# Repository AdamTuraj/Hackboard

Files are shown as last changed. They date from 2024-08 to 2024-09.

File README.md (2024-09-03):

# Title Saying Hackboard

**Every hardware hacker needs a development board. So why not make your own overkill one?**

The Hackboard is a "one board fits (almost) all" development board with many useful features to ensure it works with all projects! Whether you need to drive a motor, listen through a microphone, play music on a speaker or use various peripherals, the Hackboard has you covered.

Running on Arduino or STM32CubeIDE, you can take full advantage of Hackboard due to its low learning curve. On top of all these features, it is super efficient and can easily run off a 9v battery for many hours. Still not interested. Get a larger overview of the features below!

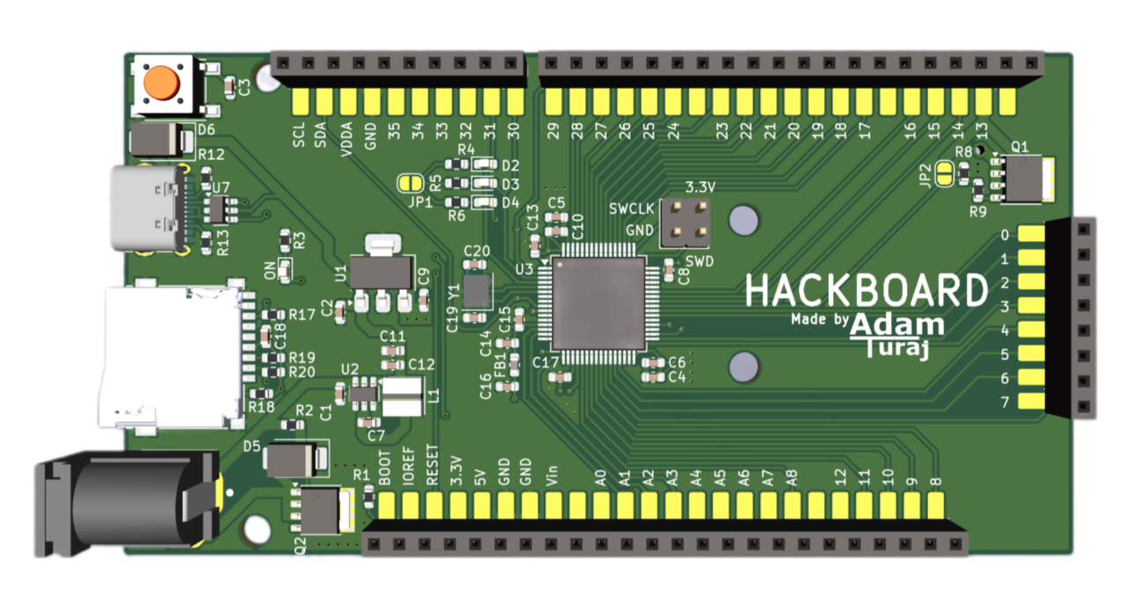
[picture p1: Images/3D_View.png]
A Top 3d view of the hackboard


Here's a deeper dive into the features:

- 80MHz Cortex M4 Core with 1 Mb of Flash and 128 Kb of SRAM
- Abilitiy to run on a 9v battery for around **150 HOURS**[^1]
- 45 GPIO pins
  - 2 SPI Interfaces[^2]
  - 1 I2C Interface
  - 1 CAN Interface
  - 1 UART Interface
  - 18 PWM Pins
  - 9 ADC's (Analog pins)
  - 2 DAC's
  - 1 OPAmp
- Arduino Uno Shield Compatible
- Same hole arrangement as Arduino UNO[^3]
- Extended header pads for easy probing
- Micro SD card slot
- PWM Addressable MOSFET capable of powering up to 54W
- 3 addressable LED's
- Barrel jack supporting up to 32V at 54W
- USB C port for flashing and power

[^1]: This assumes you are running with 0 peripherals connected, and are using a [Duracell 9v battery](https://www.duracell.com/wp-content/uploads/2016/03/MN1604_US_CT1.pdf)
[^2]: Only one may be used when an SD card is in use.
[^3]: The bottom right hole moved slightly up due to spacing issues.

## Assembly

> [!WARNING]
> This board CANNOT be assembled through JLCPCB due to many of the parts not being available at LCSC. Alternatives are using different PCB manufacturers or assembling it yourself

The BOM can be found in the production folder or the Digikey list [here](https://www.digikey.ca/en/mylists/list/BNXJM32ETT).

The extra MOSFET and related circuitry on pin 13 does not need to be soldered for the board to function (hence the DNP).

### Jumpers

JP1 and JP2 are jumpers that can be soldered/desoldered to achieve certain functionality.

JP1 must be bridged to enable the addressable LED's. JP2 must be left unbridged if the MOSFET is soldered.

### Work with Arduino

> [!NOTE]
> You must have an STLink to continue. They can be bought standalone or with a Nucleo board

A more detailed guide will be written up shortly. For now you may use [STM32Duino](https://github.com/stm32duino/Arduino_Core_STM32) to make it work with Arduino.

## Images

Schematic
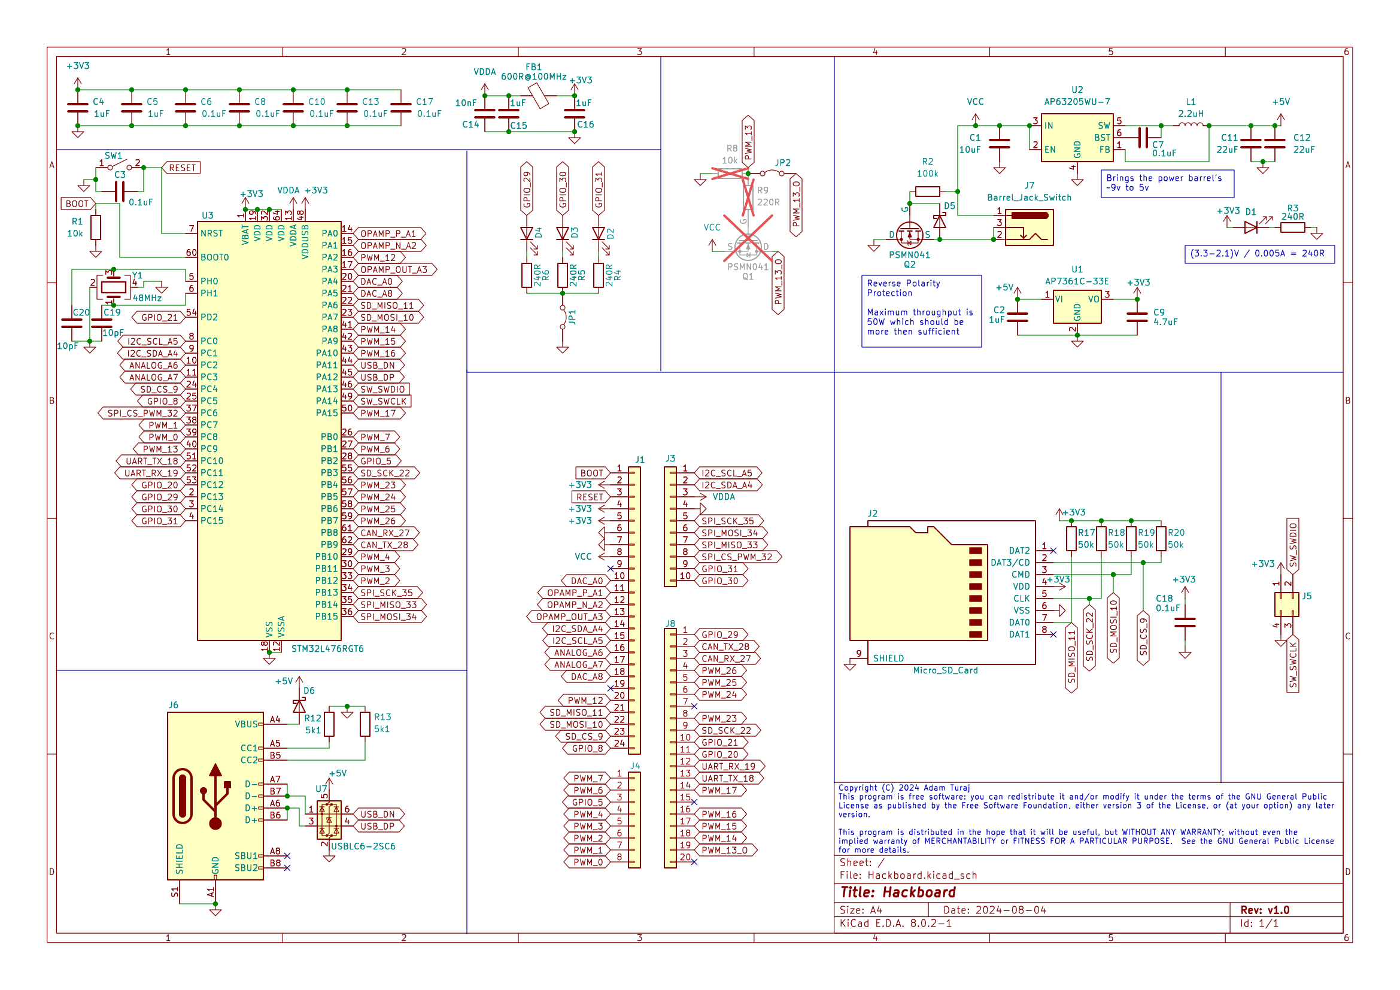
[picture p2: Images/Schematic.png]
Schematic


All Layers
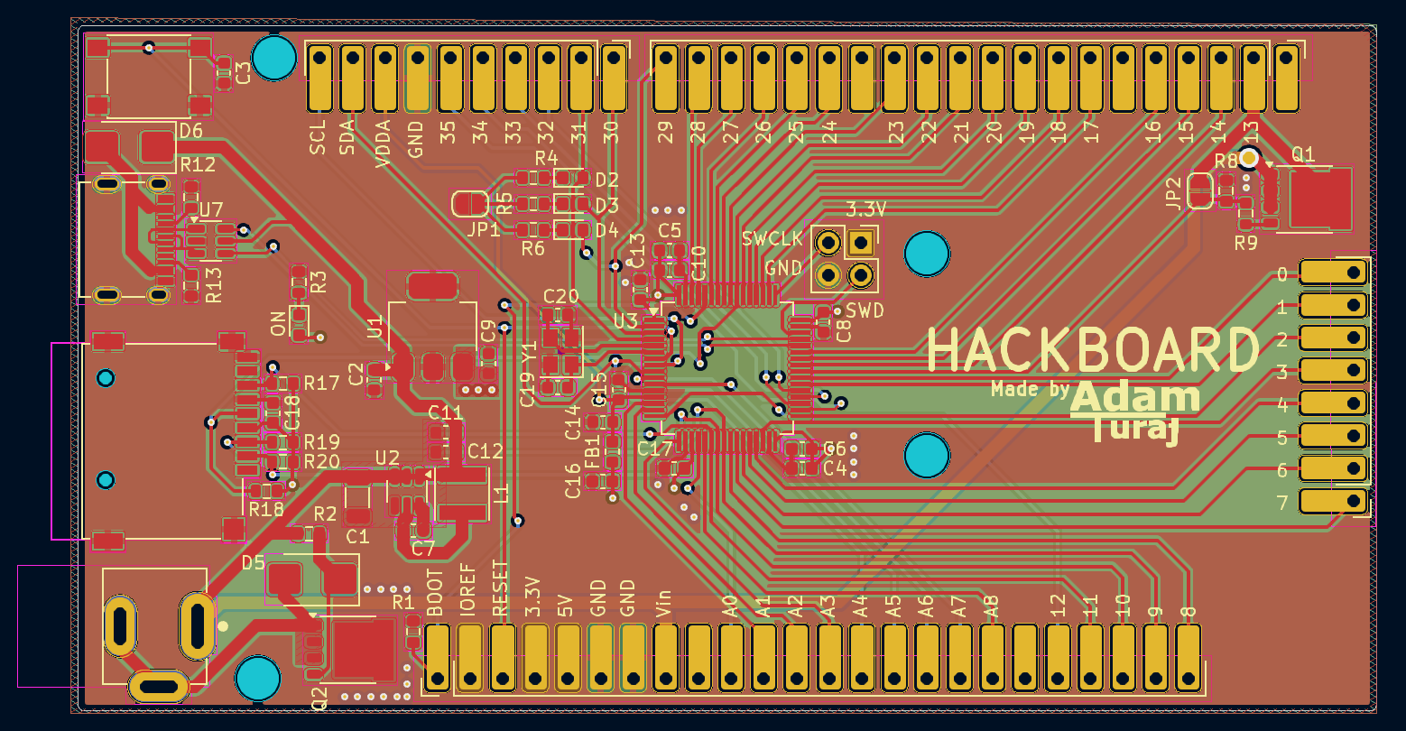
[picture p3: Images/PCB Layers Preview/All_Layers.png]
All PCB Layers


Top Layer (Signal / GND)
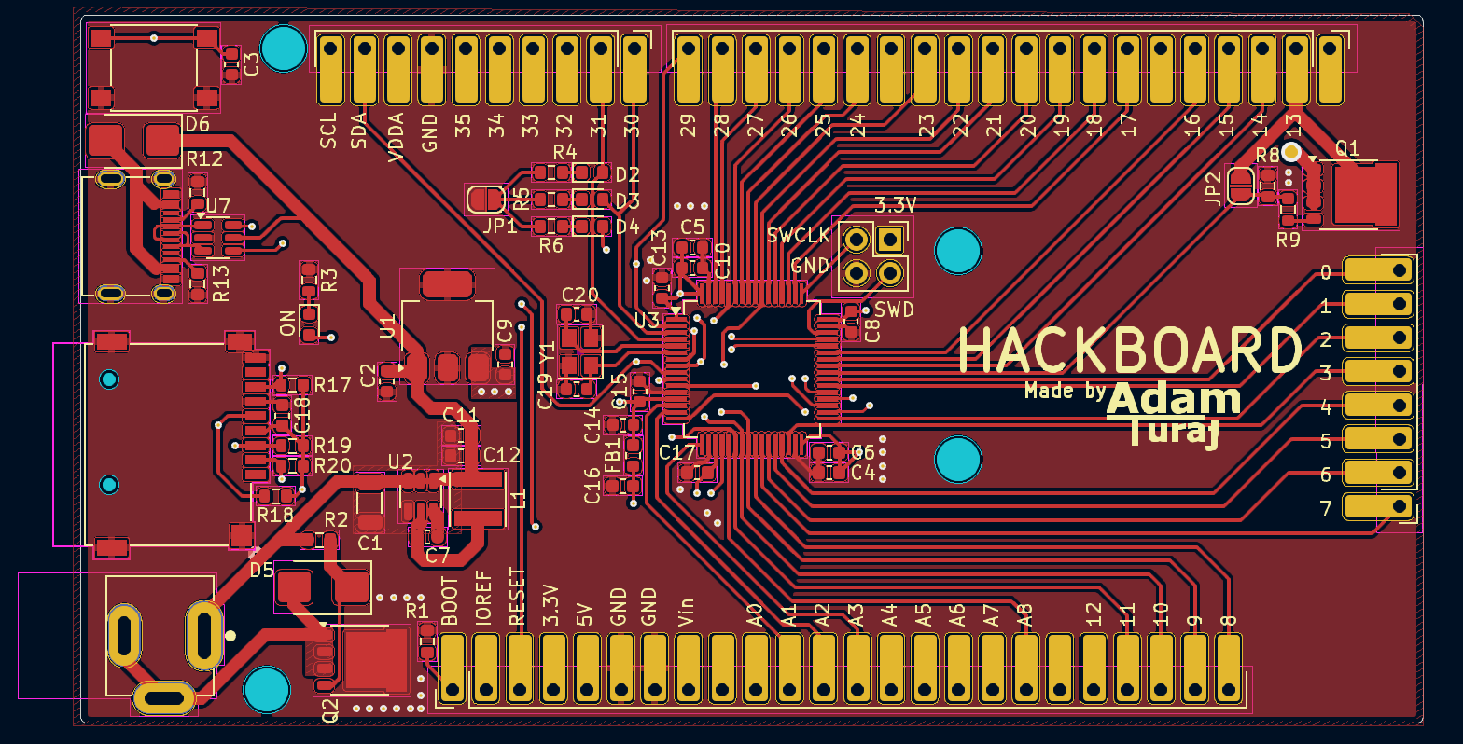
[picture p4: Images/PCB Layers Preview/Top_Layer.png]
Top PCB Layer


Second Layer (GND)
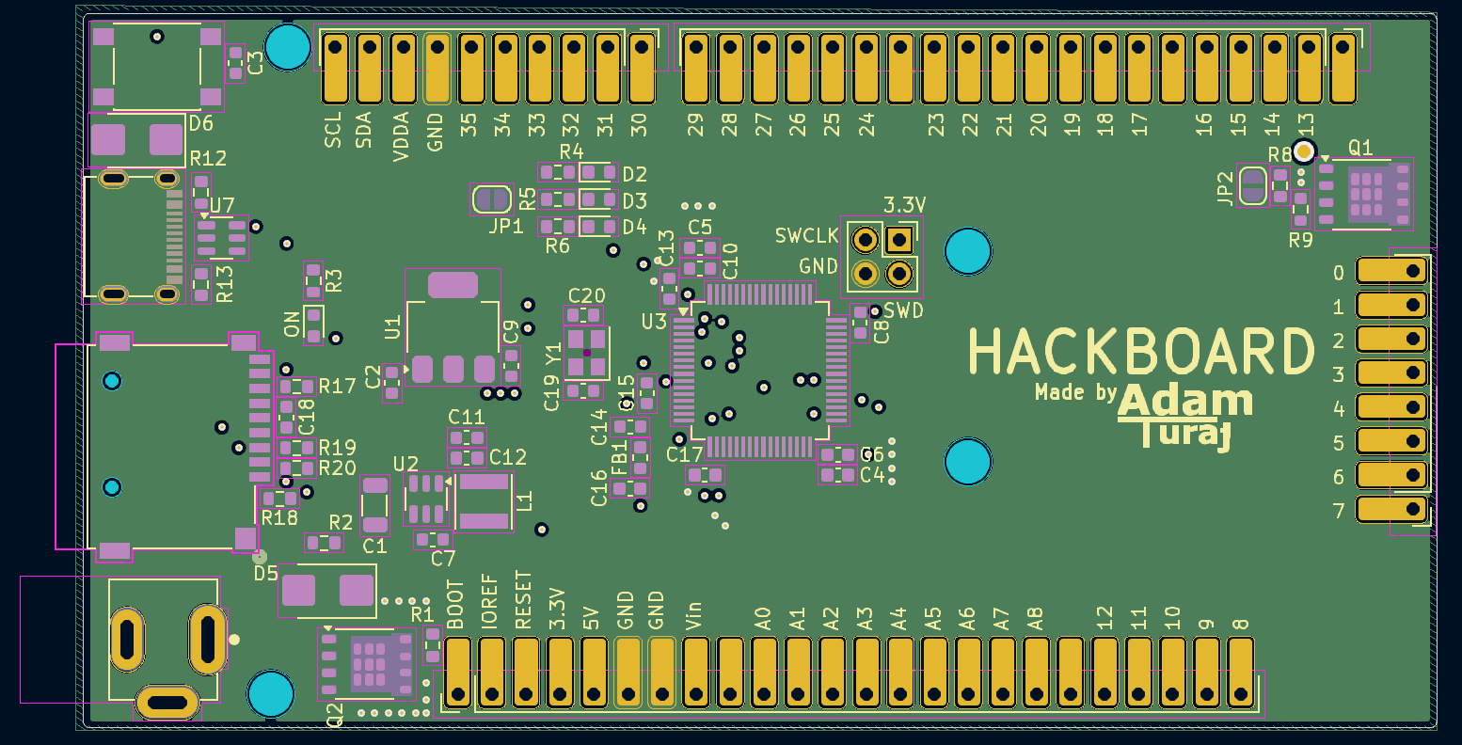
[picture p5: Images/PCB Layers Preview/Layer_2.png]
Second PCB Layer


Third Layer (Power)
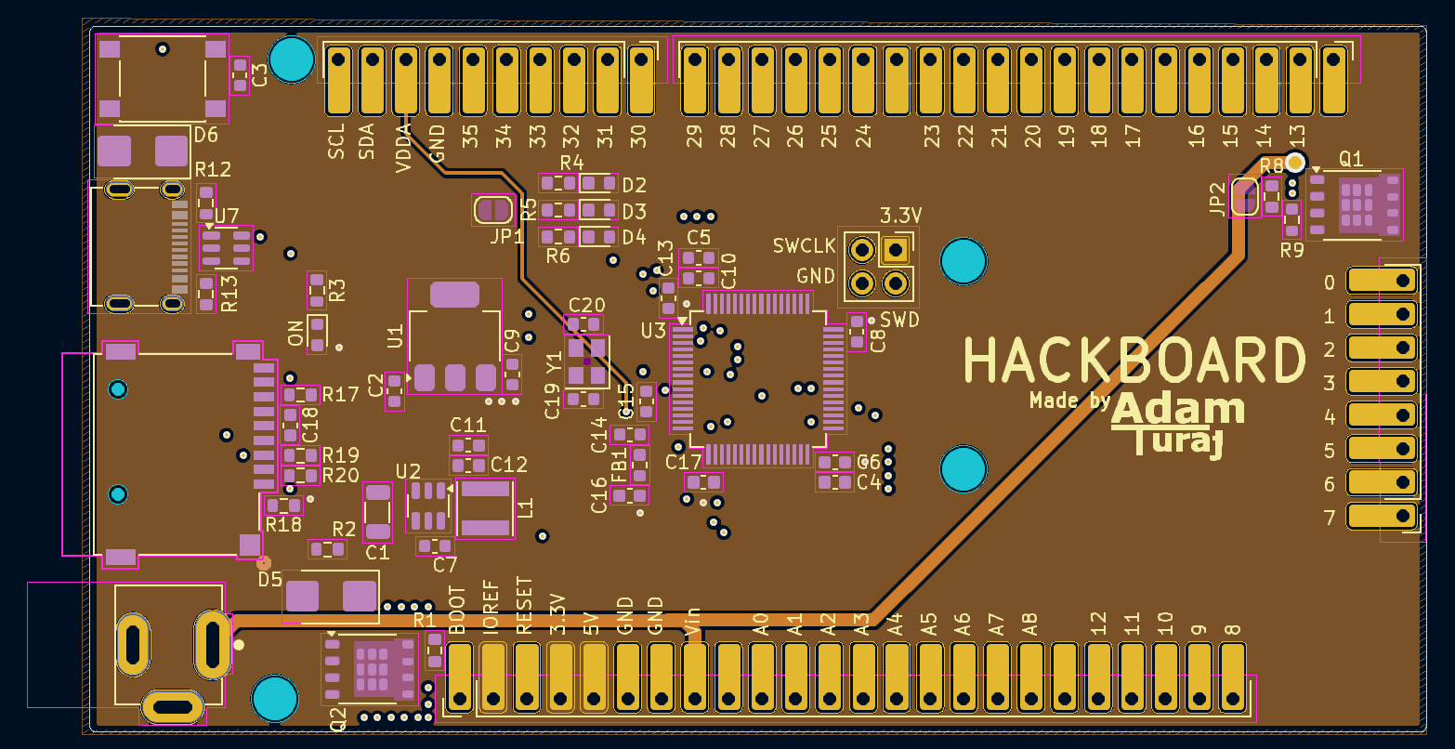
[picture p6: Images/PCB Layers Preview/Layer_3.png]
Third PCB Layer


Bottom Layer (Signal / GND)
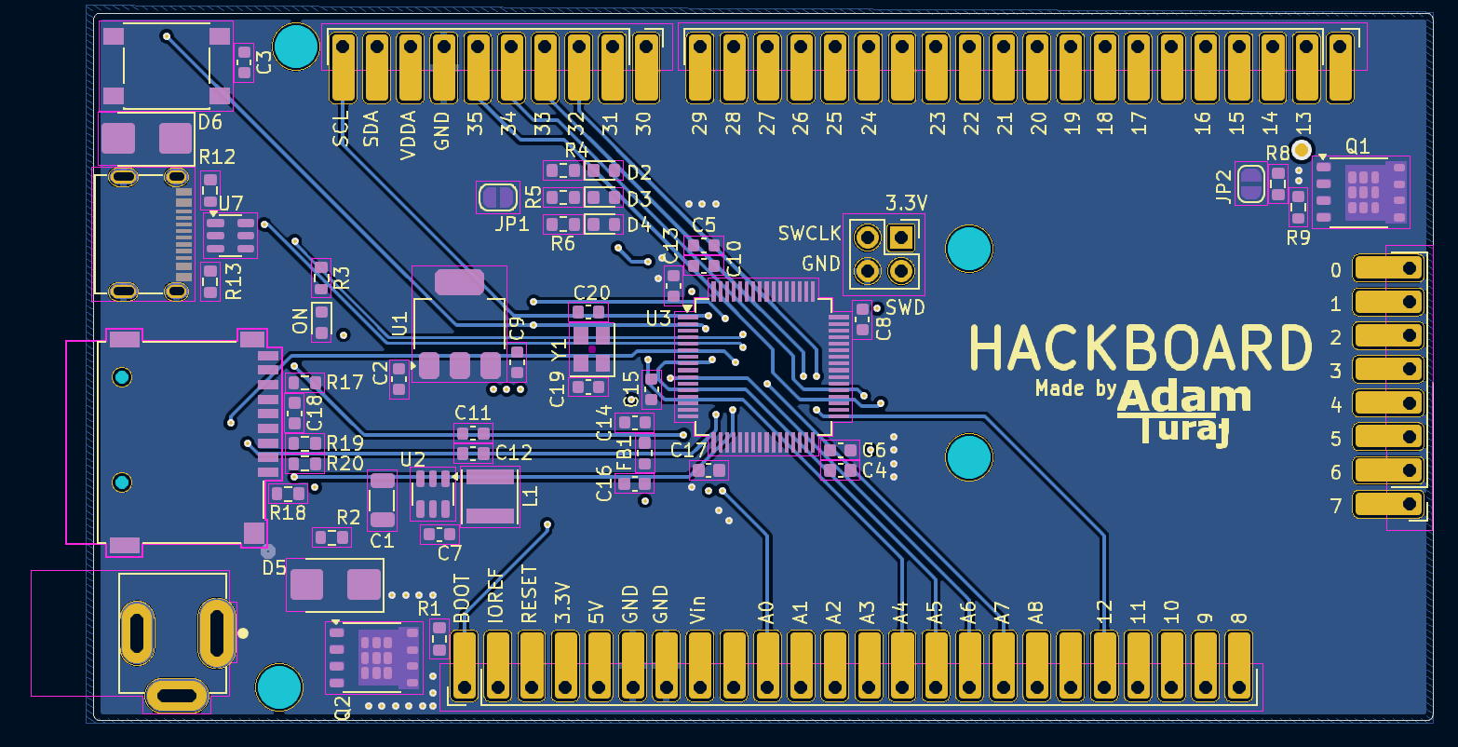
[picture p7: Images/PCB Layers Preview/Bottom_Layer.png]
Bottom PCB Layer


Bottom 3D View

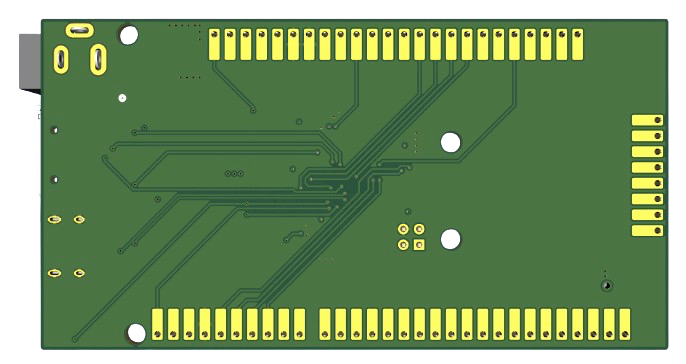
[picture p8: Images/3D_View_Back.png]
Bottom 3D View


## License

Hackboard is licensed under the GNU General Public License. See the full license text in [LICENSE](LICENSE).

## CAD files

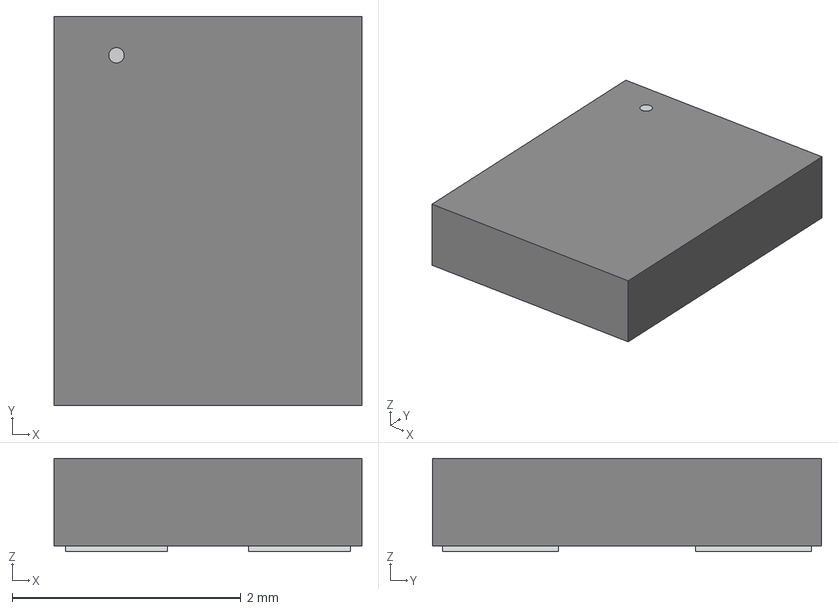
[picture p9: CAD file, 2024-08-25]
STEP/RH100_RAL.step
2.69 x 3.40 x 0.815 mm

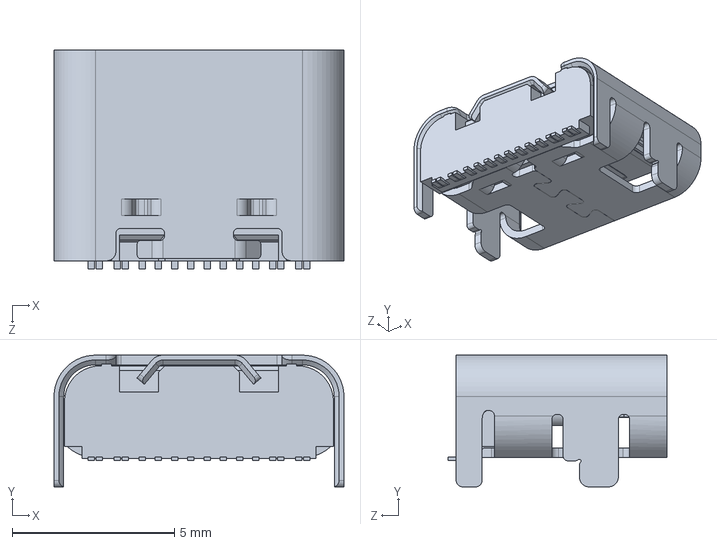
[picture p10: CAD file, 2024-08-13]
STEP/GSB1C411111DS1HR--3DModel-STEP-533217.STEP
8.94 x 4.06 x 6.75 mm

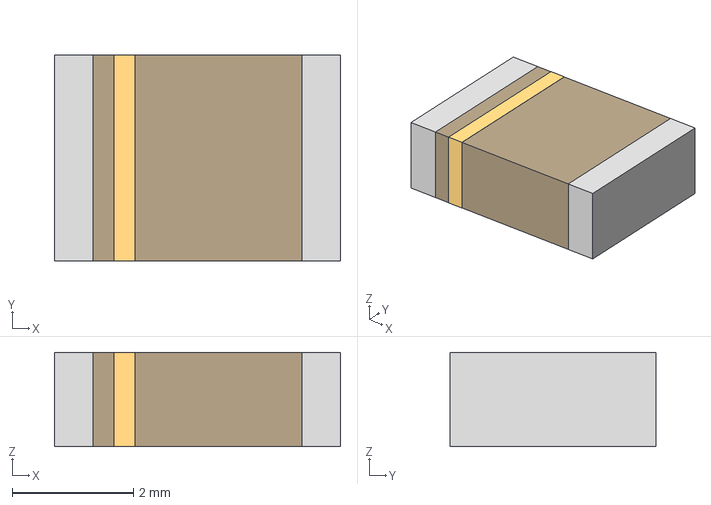
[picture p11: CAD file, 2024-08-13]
STEP/0ZCG_BEL.step
4.72 x 3.41 x 1.55 mm

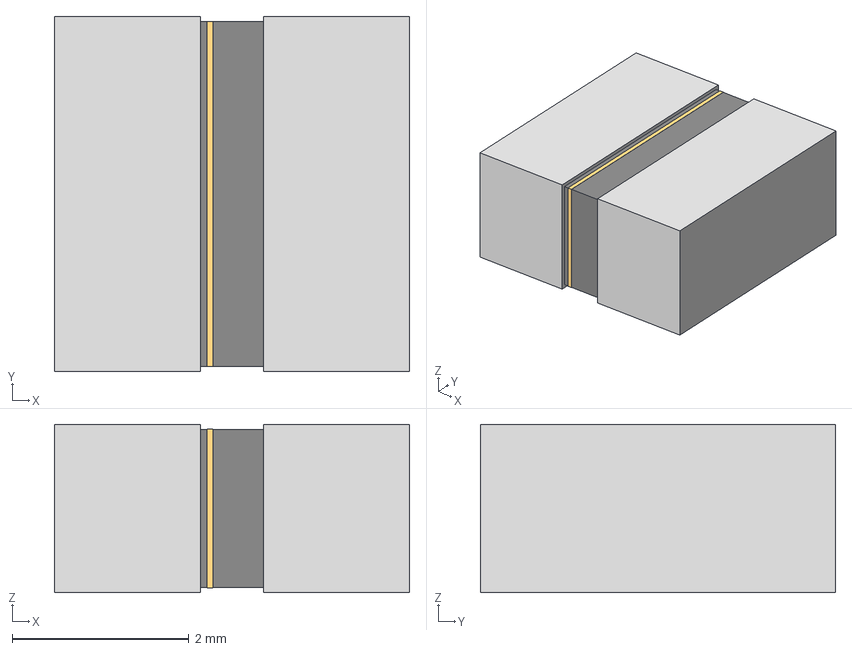
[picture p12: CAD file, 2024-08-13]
STEP/IND_IFSC_1515AH_VIS.step
4.01 x 4.01 x 1.91 mm

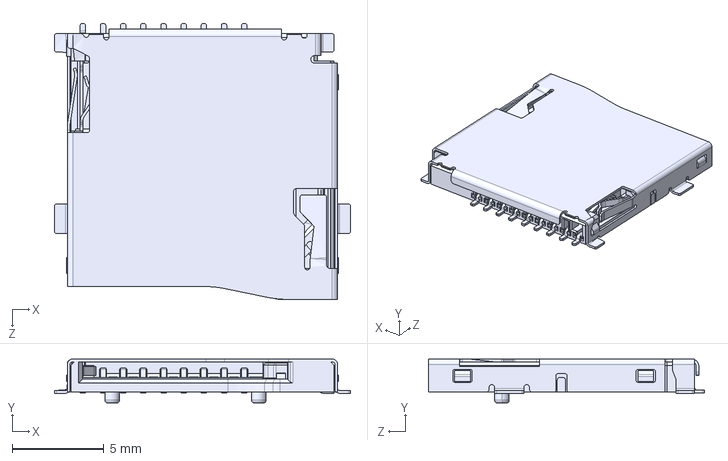
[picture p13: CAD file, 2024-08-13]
STEP/CUI_DEVICES_MSD-1-A.step
16.1 x 2.40 x 15.0 mm

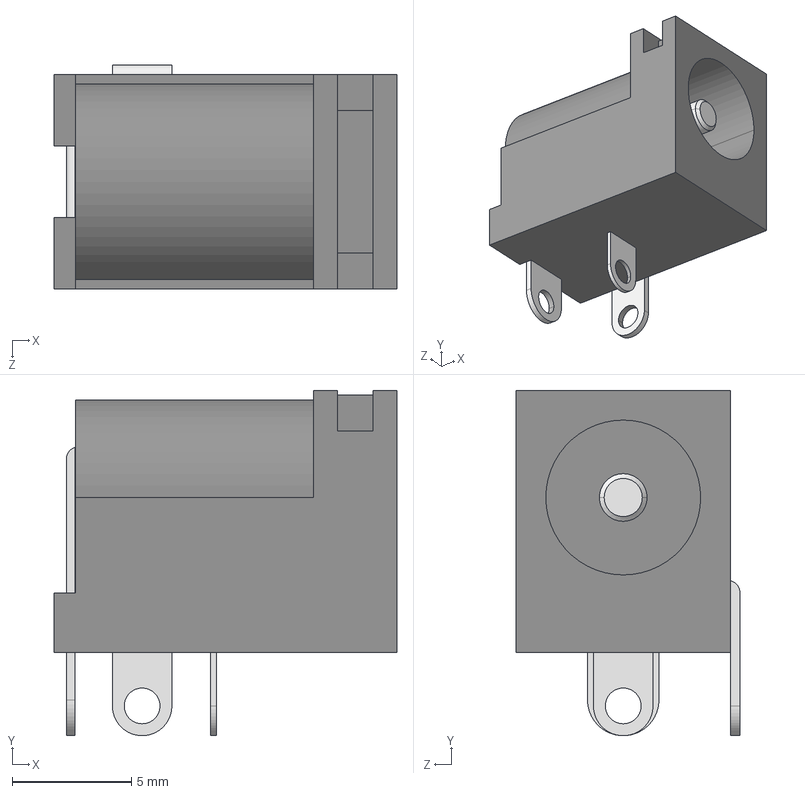
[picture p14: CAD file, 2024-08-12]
STEP/CUI_DEVICES_PJ-002AH.step
14.4 x 14.5 x 9.40 mm

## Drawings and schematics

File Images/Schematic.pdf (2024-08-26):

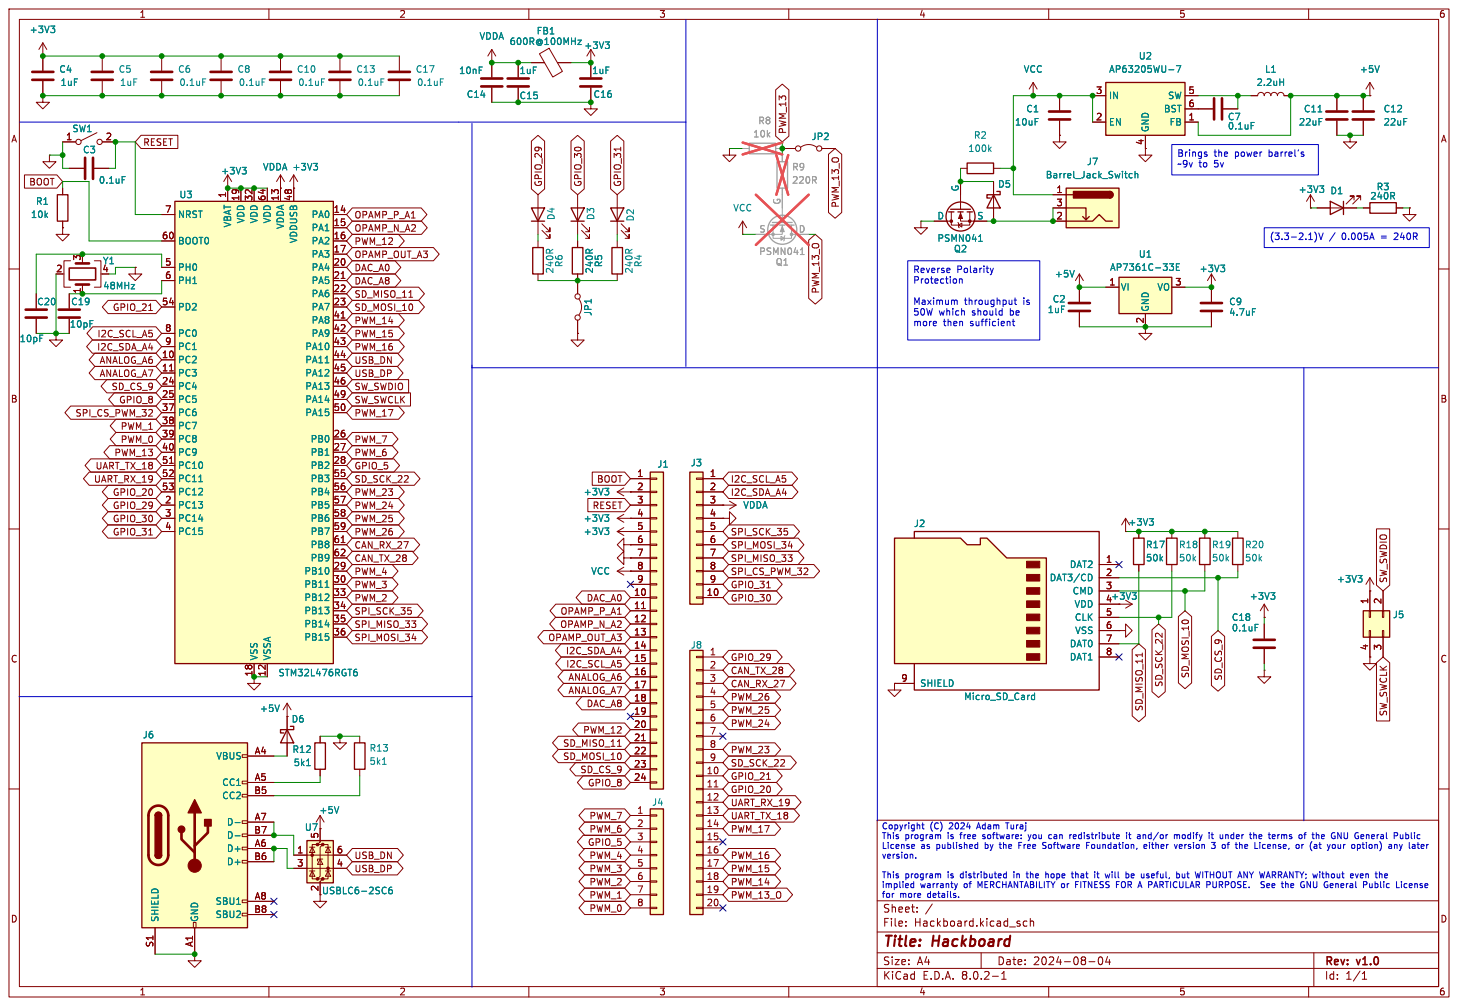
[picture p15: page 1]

Brings the power barrel's ~9v to 5v J7 Barrel_Jack_Switch

1 PC2 10 PC3 11 VSSA 12 VDDA 13 PA0 14 PA1 15 PA2 16 PA3 17 VSS 18 VDD 19 PC13 2 PA4 20 PA5 21 PA6 22 PA7 23 PC4 24 PC5 25 PB0 26 PB1 27 PB2 28 PB10 29 PC14 3 PB11 30 VDD 32 PB12 33 PB13 34 PB14 35 PB15 36 PC6 37 PC7 38 PC8 39 PC15 4 PC9 40 PA8 41 PA9 42 PA10 43 PA11 44 PA12 45 PA13 46 VDDUSB 48 PA14 49 PH0 5 PA15 50 PC10 51 PC11 52 PC12 53 PD2 54 PB3 55 PB4 56 PB5 57 PB6 58 PB7 59 PH1 6 BOOT0 60 PB8 61 PB9 62 VDD 64 NRST 7 PC0 8 PC1 9 U3 STM32L476RGT6

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

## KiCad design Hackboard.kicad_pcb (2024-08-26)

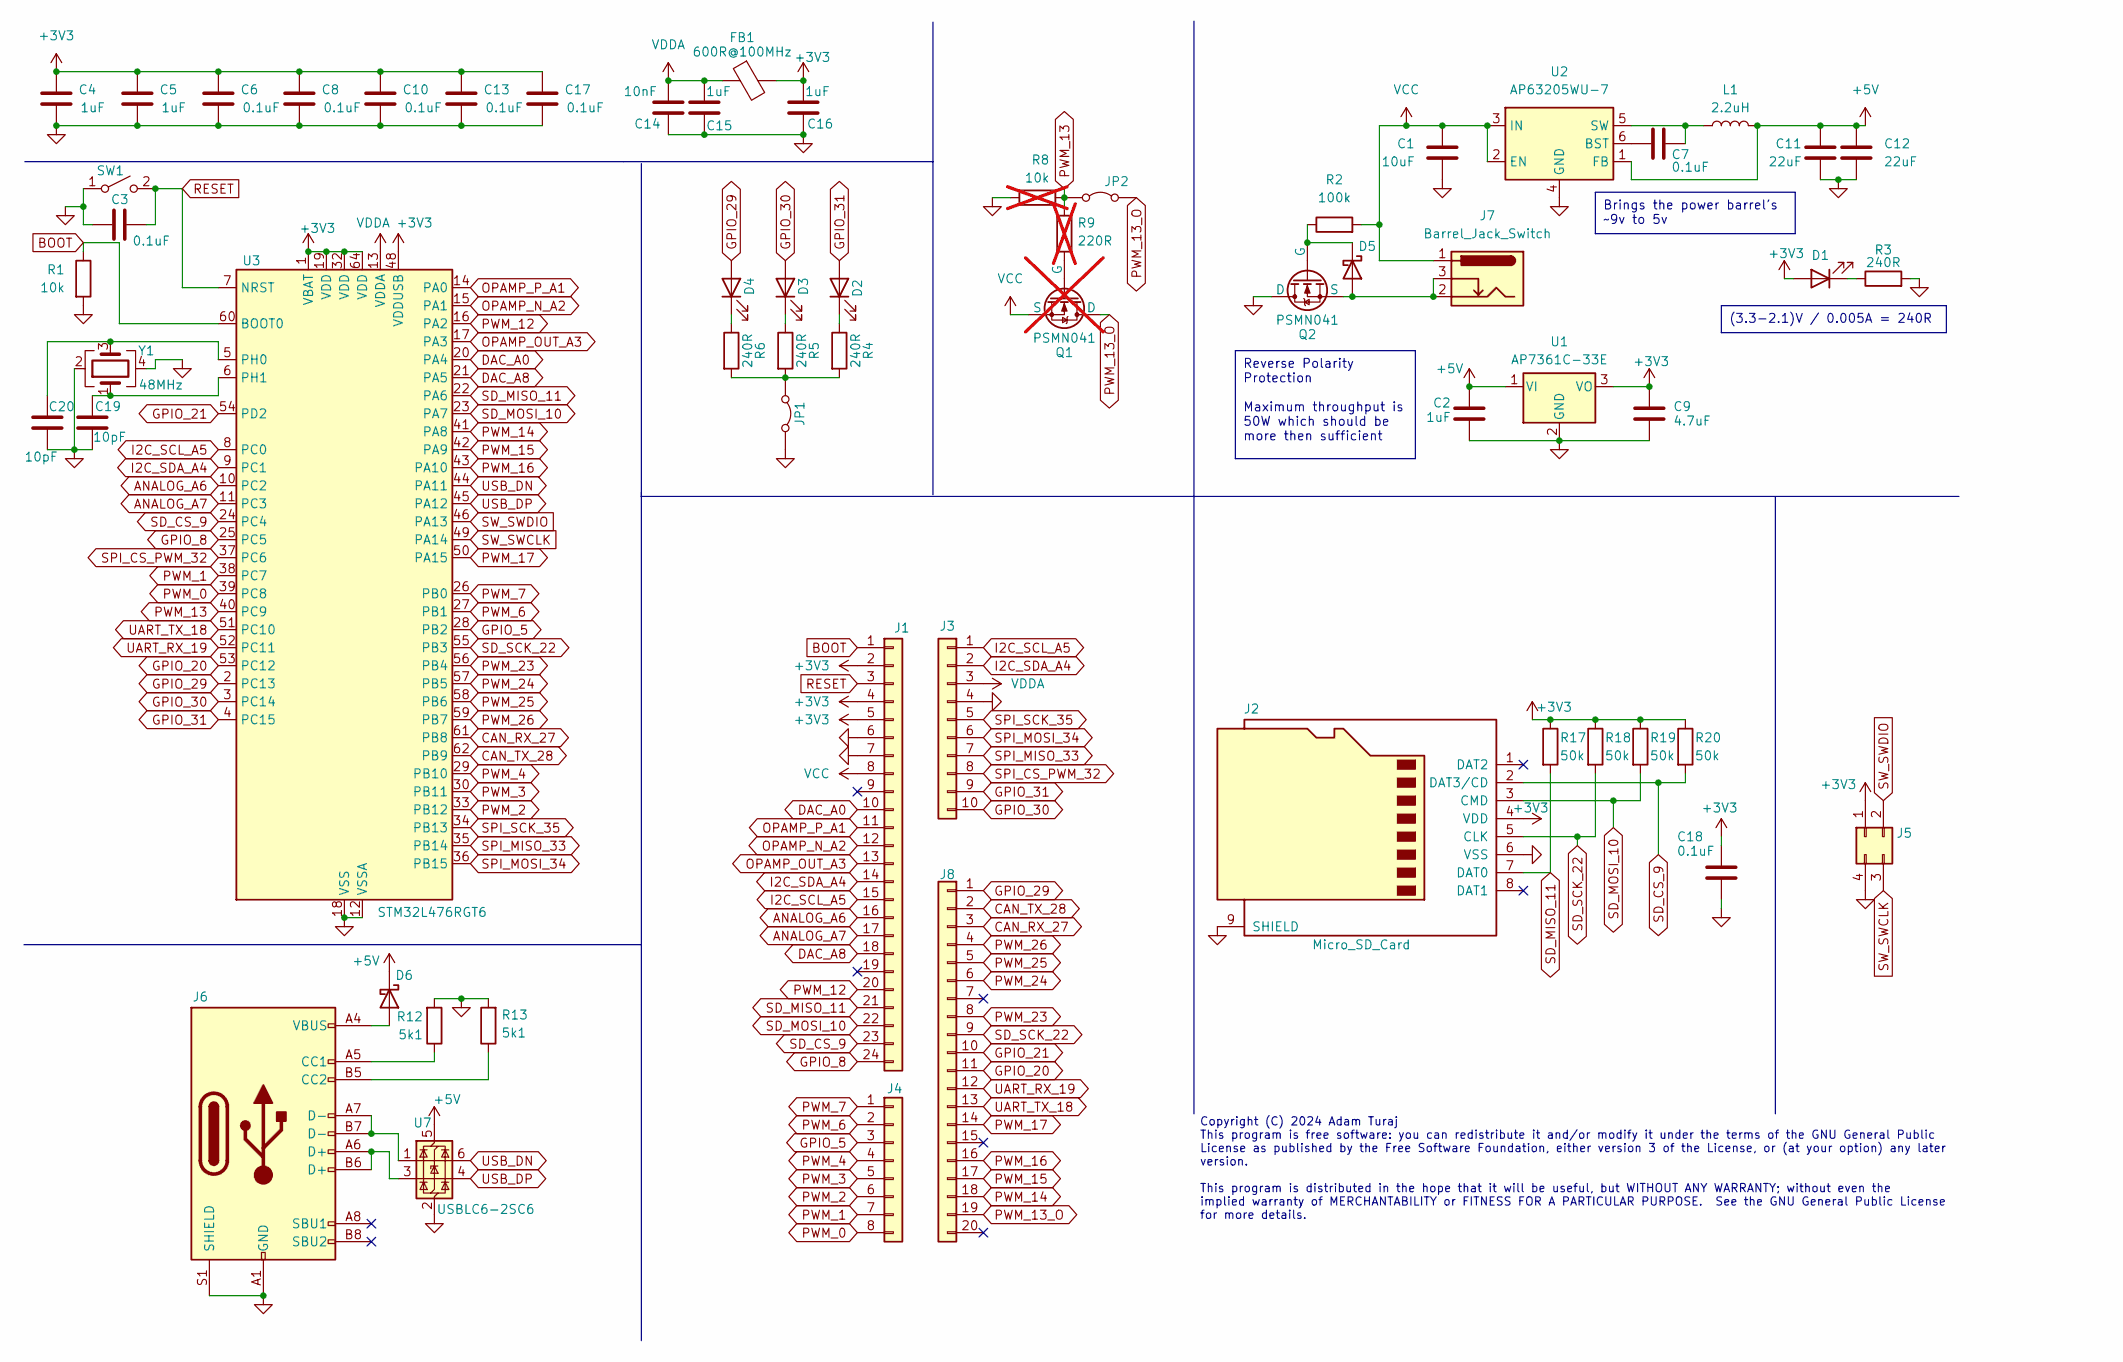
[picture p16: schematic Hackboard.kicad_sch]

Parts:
C1: 10uF; C_1206_3216Metric; MPN 0603DD106MAT2A
C2, C4, C5, C15, C16: 1uF; C_0603_1608Metric; MPN CC0603KRX7R7BB105
C3, C6, C7, C8, C10, C13, C17, C18: 0.1uF; C_0603_1608Metric; MPN GCM188R71H104KA57D
C9: 4.7uF; C_0603_1608Metric; MPN AP7361-33E-13
C11, C12: 22uF; C_0603_1608Metric; MPN C1608X5R1A226M080AC
C14: 10nF; C_0603_1608Metric; MPN 0603B103K500CT
C19, C20: 10pF; C_0603_1608Metric; MPN 0603N100J500CT
D1, D3: LED; LED_0603_1608Metric; MPN LTST-C190GKT
D2: LED; LED_0603_1608Metric; MPN LTST-C190TBKT
D4: LED; LED_0603_1608Metric; MPN LTST-C191KRKT
D5, D6: D_Schottky; D_SMB; MPN SSB44-E3/52T
FB1: 600R@100MHz; L_0603_1608Metric; MPN BLM18AG601SN1D
J1: Conn_01x24; PinSocket_1x24_P2.54mm_Vertical; MPN PPTC241LFBN-RC
J2: Micro_SD_Card; CONN9_MSD-1_CUD; MPN MSD-1-A
J3: Conn_01x10; PinSocket_1x10_P2.54mm_Vertical; MPN PPPC101LFBN-RC
J4: Conn_01x08; PinSocket_1x08_P2.54mm_Vertical; MPN 61300811821
J5: Conn_02x02_Counter_Clockwise; PinHeader_2x02_P2.54mm_Vertical
J6: USB_C_Receptacle_USB2.0_16P; USB_C_Receptacle_Amphenol_GSB1C4; MPN GSB1C411111DS1HR
J7: Barrel_Jack_Switch; CUI_PJ-002AH; MPN PJ-002AH
J8: Conn_01x20; PinSocket_1x20_P2.54mm_Vertical; MPN 61302011821
JP1, JP2: Jumper_2_Bridged; SolderJumper-2_P1.3mm_Open_RoundedPad1.0x1.5mm; MPN PPPC022LFBN-RC
L1: 2.2uH; L_Vishay_IFSC-1515AH_4x4x1.8mm; MPN IFSC1515AHER2R2M01
Q1: PSMN041; LFPAK56; MPN PSMN041-80YLX; not fitted
Q2: PSMN041; LFPAK56; MPN PSMN041-80YLX
R1: 10k; R_0603_1608Metric; MPN RMCF0603JT10K0
R2: 100k; R_0603_1608Metric; MPN ERJ-3EKF1003V
R3, R4, R5, R6: 240R; R_0603_1608Metric; MPN CRGCQ0603J220R
R8: 10k; R_0603_1608Metric; MPN RMCF0603JT10K0; not fitted
R9: 220R; R_0603_1608Metric; MPN CRGCQ0603J220R; not fitted
R12, R13: 5k1; R_0603_1608Metric; MPN RC0603FR-075K1L
R17, R18, R19, R20: 50k; R_0603_1608Metric; MPN RT0603BRD0750KL
SW1: SW_SPST; SW_SPST_PTS645; MPN PTS645SK43SMTR92 LFS
U1: AP7361C-33E; SOT-223-3_TabPin2; MPN AP7361C-33E-13
U2: AP63205WU-7; TSOT-23-6; MPN AP63205WU-7
U3: STM32L476RGT6; LQFP-64_10x10mm_P0.5mm; MPN STM32L476RGT6
U7: USBLC6-2SC6; SOT-23-6; MPN USBLC6-2SC6
Y1: 48MHz; Oscillator_SMD_Abracon_ASE-4Pin_3.2x2.5mm; MPN RH100-48.000-8-F-1015-EXT-TR

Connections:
+3V3: C4.1, C5.1, C6.1, C8.1, C9.2, C10.1, C13.1, C16.2, C17.1, C18.1, D1.2 (A), FB1.2, J1.2, J1.4, J1.5, J2.4 (VDD), J5.1, R17.1, R18.1, R19.1, R20.1, U1.3 (VO), U3.1 (VBAT), U3.19 (VDD), U3.32 (VDD), U3.48 (VDDUSB), U3.64 (VDD)
+5V: C2.1, C11.1, C12.1, D6.1 (K), L1.2, U1.1 (VI), U2.1 (FB), U7.5 (VBUS)
ANALOG_A6: J1.16, U3.10 (PC2)
ANALOG_A7: J1.17, U3.11 (PC3)
BOOT: J1.1, R1.1, U3.60 (BOOT0)
CAN_RX_27: J8.3, U3.61 (PB8)
CAN_TX_28: J8.2, U3.62 (PB9)
DAC_A0: J1.10, U3.20 (PA4)
DAC_A8: J1.18, U3.21 (PA5)
GND: C1.2, C2.2, C3.2, C4.2, C5.2, C6.2, C8.2, C9.1, C10.2, C11.2, C12.2, C13.2, C14.1, C15.1, C16.1, C17.2, C18.2, C19.2, C20.2, J1.6, J1.7, J2.6 (VSS), J2.9 (SHIELD), J3.4, J5.4, J6.A1 (GND), J6.A12 (GND), J6.B1 (GND), J6.B12 (GND), J6.S1 (SHIELD), JP1.1 (A), Q2.1 (D), R1.2, R3.2, R8.2, R12.2, R13.2, SW1.1 (A), U1.2 (GND), U2.4 (GND), U3.12 (VSSA), U3.18 (VSS), U3.31 (VSS), U3.47 (VSS), U3.63 (VSS), U7.2 (GND), Y1.2, Y1.4
GPIO_5: J4.3, U3.28 (PB2)
GPIO_8: J1.24, U3.25 (PC5)
GPIO_20: J8.11, U3.53 (PC12)
GPIO_21: J8.10, U3.54 (PD2)
GPIO_29: D4.2 (A), J8.1, U3.2 (PC13)
GPIO_30: D3.2 (A), J3.10, U3.3 (PC14)
GPIO_31: D2.2 (A), J3.9, U3.4 (PC15)
I2C_SCL_A5: J1.15, J3.1, U3.8 (PC0)
I2C_SDA_A4: J1.14, J3.2, U3.9 (PC1)
unnamed: D1.1 (K), R3.1
unnamed: D2.1 (K), R4.1
unnamed: D3.1 (K), R5.1
unnamed: D4.1 (K), R6.1
unnamed: D5.2 (A), J7.2, J7.3, Q2.3 (S)
unnamed: D5.1 (K), Q2.2 (G), R2.1
unnamed: D6.2 (A), J6.A4 (VBUS), J6.A9 (VBUS), J6.B4 (VBUS), J6.B9 (VBUS)
unnamed: J6.A5 (CC1), R12.1
unnamed: J6.B5 (CC2), R13.1
unnamed: J6.A6 (D+), J6.B6 (D+), U7.3 (I/O2)
unnamed: J6.A7 (D-), J6.B7 (D-), U7.1 (I/O1)
unnamed: JP1.2 (B), R4.2, R5.2, R6.2
unnamed: Q1.2 (G), R9.1
unnamed: C7.1, U2.6 (BST)
unnamed: C7.2, L1.1, U2.5 (SW)
unnamed: C20.1, U3.5 (PH0), Y1.3
unnamed: C19.1, U3.6 (PH1), Y1.1
OPAMP_N_A2: J1.12, U3.15 (PA1)
OPAMP_OUT_A3: J1.13, U3.17 (PA3)
OPAMP_P_A1: J1.11, U3.14 (PA0)
PWM_0: J4.8, U3.39 (PC8)
PWM_1: J4.7, U3.38 (PC7)
PWM_2: J4.6, U3.33 (PB12)
PWM_3: J4.5, U3.30 (PB11)
PWM_4: J4.4, U3.29 (PB10)
PWM_6: J4.2, U3.27 (PB1)
PWM_7: J4.1, U3.26 (PB0)
PWM_12: J1.20, U3.16 (PA2)
PWM_13: JP2.1 (A), R8.1, R9.2, U3.40 (PC9)
PWM_13_O: J8.19, JP2.2 (B), Q1.1 (D)
PWM_14: J8.18, U3.41 (PA8)
PWM_15: J8.17, U3.42 (PA9)
PWM_16: J8.16, U3.43 (PA10)
PWM_17: J8.14, U3.50 (PA15)
PWM_23: J8.8, U3.56 (PB4)
PWM_24: J8.6, U3.57 (PB5)
PWM_25: J8.5, U3.58 (PB6)
PWM_26: J8.4, U3.59 (PB7)
RESET: C3.1, J1.3, SW1.2 (B), U3.7 (NRST)
SD_CS_9: J1.23, J2.2 (DAT3/CD), R20.2, U3.24 (PC4)
SD_MISO_11: J1.21, J2.7 (DAT0), R17.2, U3.22 (PA6)
SD_MOSI_10: J1.22, J2.3 (CMD), R19.2, U3.23 (PA7)
SD_SCK_22: J2.5 (CLK), J8.9, R18.2, U3.55 (PB3)
SPI_CS_PWM_32: J3.8, U3.37 (PC6)
SPI_MISO_33: J3.7, U3.35 (PB14)
SPI_MOSI_34: J3.6, U3.36 (PB15)
SPI_SCK_35: J3.5, U3.34 (PB13)
SW_SWCLK: J5.3, U3.49 (PA14)
SW_SWDIO: J5.2, U3.46 (PA13)
UART_RX_19: J8.12, U3.52 (PC11)
UART_TX_18: J8.13, U3.51 (PC10)
USB_DN: U3.44 (PA11), U7.6 (I/O1)
USB_DP: U3.45 (PA12), U7.4 (I/O2)
VCC: C1.1, J1.8, J7.1, Q1.3 (S), R2.2, U2.2 (EN), U2.3 (IN)
VDDA: C14.2, C15.2, FB1.1, J3.3, U3.13 (VDDA)

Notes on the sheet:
Brings the power barrel's ~9v to 5v
Reverse Polarity Protection Maximum throughput is 50W which should be more then sufficient
(3.3-2.1)V / 0.005A = 240R
Copyright (C) 2024 Adam Turaj This program is free software: you can redistribute it and/or modify it under the terms of the GNU General Public License as published by the Free Software Foundation, either version 3 of the License, or (at your option) any later version. This program is distributed i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

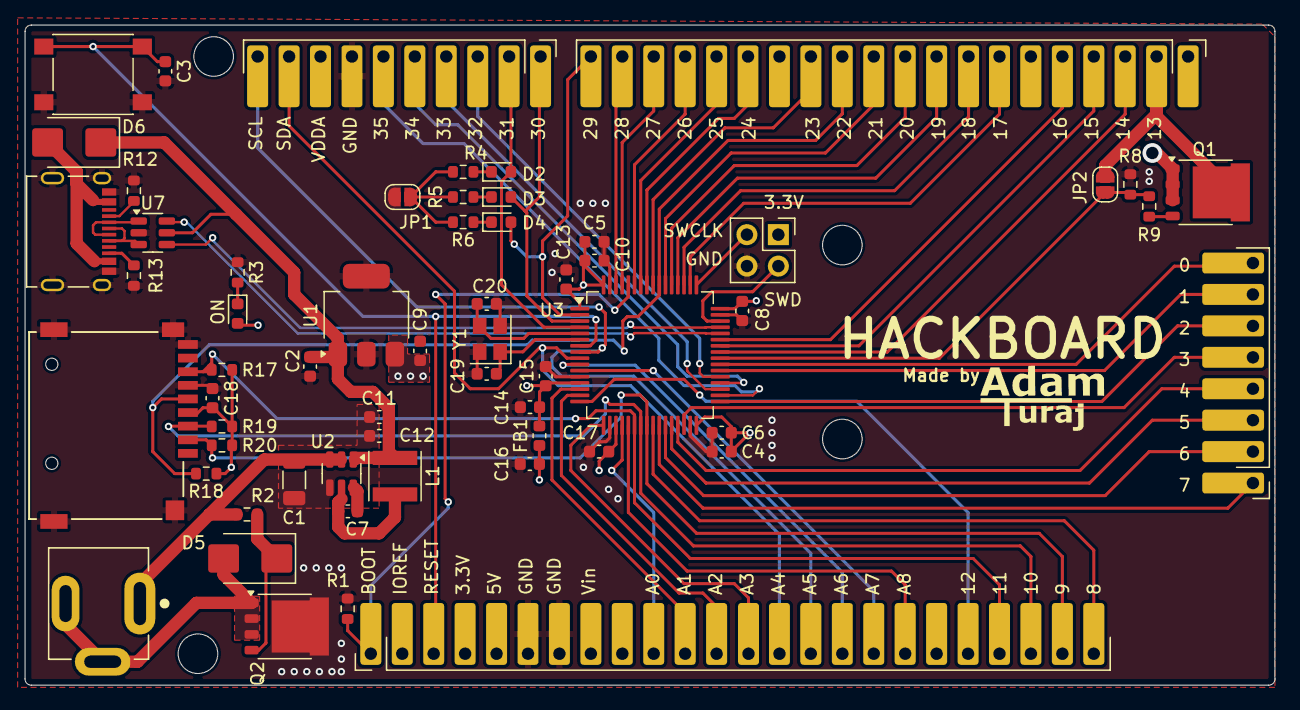
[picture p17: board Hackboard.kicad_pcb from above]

Board: 4 copper layers, 101.0 x 53.3 mm, 64 parts (0 on the bottom side), 74 nets.

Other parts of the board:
H1, H2, H3, H4: MountingHole; MountingHole_3.2mm_M3

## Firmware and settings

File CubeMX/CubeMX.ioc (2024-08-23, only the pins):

Mcu.UserName=STM32L476RGTx
PA0.GPIO_Label=OPAMP_P_A1
PA0.Signal=OPAMP1_VINP
PA1.GPIO_Label=OPAMP_N_A2
PA1.Signal=OPAMP1_VINM
PA10.GPIO_Label=PWM_16
PA10.Signal=S_TIM1_CH3
PA11.GPIO_Label=USB_DM_17
PA11.Signal=USB_OTG_FS_DM
PA12.GPIO_Label=USB_DP_18
PA12.Signal=USB_OTG_FS_DP
PA2.GPIO_Label=PWM_12
PA2.Signal=S_TIM5_CH3
PA3.GPIO_Label=OPAMP_OUT_A3
PA3.Signal=OPAMP1_VOUT
PA4.GPIO_Label=DAC_A0
PA4.Signal=COMP_DAC11_group
PA5.GPIO_Label=DAC_A8
PA5.Signal=COMP_DAC12_group
PA6.GPIO_Label=SD_MISO_11
PA6.Signal=SPI1_MISO
PA7.GPIO_Label=SD_MOSI_10
PA7.Signal=SPI1_MOSI
PA8.GPIO_Label=PWM_14
PA8.Signal=S_TIM1_CH1
PA9.GPIO_Label=PWM_13
PA9.Signal=S_TIM1_CH2
PB0.GPIO_Label=PWM_7
PB0.Signal=S_TIM3_CH3
PB1.GPIO_Label=PWM_6
PB1.Signal=S_TIM3_CH4
PB10.GPIO_Label=PWM_4
PB10.Signal=S_TIM2_CH3
PB11.GPIO_Label=PWM_3
PB11.Signal=S_TIM2_CH4
PB12.GPIO_Label=PWM_2
PB12.Signal=GPIO_Output
PB13.GPIO_Label=SPI_SCK_38
PB13.Signal=SPI2_SCK
PB14.GPIO_Label=SPI_MISO_36
PB14.Signal=SPI2_MISO
PB15.GPIO_Label=SPI_MOSI_37
PB15.Signal=SPI2_MOSI
PB2.GPIO_Label=GPIO_5
PB2.Signal=GPIO_Output
PB5.GPIO_Label=PWM_29
PB5.Signal=S_TIM3_CH2
PB6.GPIO_Label=PWM_28
PB6.Signal=S_TIM4_CH1
PB7.GPIO_Label=PWM_27
PB7.Signal=S_TIM4_CH2
PB8.GPIO_Label=CAN_RX_26
PB8.Signal=CAN1_RX
PB9.GPIO_Label=CAM_TX_25
PB9.Signal=CAN1_TX
PC0.GPIO_Label=SCL_A5
PC0.Signal=I2C3_SCL
PC1.GPIO_Label=SDA_A4
PC1.Signal=I2C3_SDA
PC10.GPIO_Label=UART_TX_20
PC10.Signal=UART4_TX
PC11.GPIO_Label=UART_RX_21
PC11.Signal=UART4_RX
PC12.GPIO_Label=GPIO_22
PC12.Signal=GPIO_Output
PC13.GPIO_Label=GPIO_24
PC13.Signal=GPIO_Output
PC2.GPIO_Label=A6
PC2.Signal=ADCx_IN3
PC3.GPIO_Label=A7
PC3.Signal=ADCx_IN4
PC4.GPIO_Label=SD_CS_9
PC4.Signal=GPIO_Output
PC5.GPIO_Label=GPIO_8
PC5.Signal=GPIO_Output
PC6.GPIO_Label=PWM_SPI_CS_35
PC6.Signal=S_TIM8_CH1
PC7.GPIO_Label=PWM_1
PC7.Signal=S_TIM8_CH2
PC8.GPIO_Label=PWM_0
PC8.Signal=S_TIM8_CH3
PC9.GPIO_Label=PWM_15
PC9.Signal=S_TIM8_CH4
PD2.GPIO_Label=GPIO_23
PD2.Signal=GPIO_Output

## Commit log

2024-08-01 First push
    [Hackboard.kicad_pcb, Hackboard.kicad_sch]
2024-08-01 Update README; Add power line and SPI for Micro SD
    [Hackboard.kicad_sch]
2024-08-01 Add USB, SD Card, LED's and other small things
    [Hackboard.kicad_sch]
2024-08-04 Make some power changes, add logic shifters
    [Hackboard.kicad_sch]
2024-08-04 Finish schematic
    [Hackboard.kicad_sch]
2024-08-06 Make changes to schematic and start adding footprints
    [Hackboard.kicad_sch]
2024-08-06 Finish footprints and place initial footprints on PCB editor
    [Hackboard.kicad_pcb, Hackboard.kicad_sch]
2024-08-06 Make basis of out line and start placing components
    [Hackboard.kicad_pcb, Hackboard.kicad_sch]
2024-08-07 Continue Laying down parts
    [Hackboard.kicad_pcb, Hackboard.kicad_sch]
2024-08-08 Start routing PCB
    [Hackboard.kicad_pcb]
2024-08-08 Continue tracing
    [Hackboard.kicad_pcb]
2024-08-08 Finish tracing MCU pins
    [Hackboard.kicad_pcb]
2024-08-09 Route power
    [Hackboard.kicad_pcb, Hackboard.kicad_sch]
2024-08-09 Change USB C footprint, fix DRC errors, adjust silkscreen
    [Hackboard.kicad_pcb, Hackboard.kicad_sch]
2024-08-10 Finish PCB
    [Hackboard.kicad_pcb, Hackboard.kicad_sch]
2024-08-10 Change MCU Pinout
    [Hackboard.kicad_sch]
2024-08-11 Finish up updated schematic, start outlining border
    [Hackboard.kicad_pcb, Hackboard.kicad_sch]
2024-08-12 Finish board layout
    [CUI_DEVICES_PJ-002AH.step, Hackboard.kicad_pcb, Hackboard.kicad_sch]
2024-08-12 Adjust pinout
    [Hackboard.kicad_pcb, Hackboard.kicad_sch]
2024-08-13 Finish tracing most digital lines
    [Hackboard.kicad_pcb, Hackboard.kicad_sch]
2024-08-13 Finish tracing all pins, start tracing power
    [Hackboard.kicad_pcb, Hackboard.kicad_sch]
2024-08-13 Finish tracing power, add STEP files
    [2169900003.stp, CUI_DEVICES_MSD-1-A.step, Hackboard.kicad_pcb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]
2024-08-13 Change connector size, change USB port, add 3d models, add final touches
    [0ZCG_BEL.step, 2169900003.stp, GSB1C411111DS1HR--3DModel-STEP-533217.STEP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]
2024-08-13 Change out LDO, add JLC parts
    [Hackboard.kicad_pcb, Hackboard.kicad_sch]
2024-08-14 Add some JLC parts
    [Hackboard.kicad_sch]
2024-08-22 Add reverse polarity protection, remove logic shifters, make misc changes to schematic
    [Hackboard.kicad_sch]
2024-08-22 Finish making changes to schematic
    [Hackboard.kicad_sch]
2024-08-23 Make changes to header, align headers and holes, start tracing
    [Hackboard.kicad_pcb, Hackboard.kicad_sch]
2024-08-24 Adjust pinout, start tracing
    [Hackboard.kicad_pcb, Hackboard.kicad_sch]
2024-08-24 Continue routing
    [Hackboard.kicad_pcb, Hackboard.kicad_sch]
2024-08-24 Continue tracing, switch MOSFET's and diodes
    [Hackboard.kicad_pcb, Hackboard.kicad_sch]
2024-08-25 Finish tracing
    [Hackboard.kicad_pcb, RH100_RAL.step]
2024-08-25 Fix footprint for HSE, add logo and updated schematic
    [Hackboard.kicad_pcb, Hackboard.kicad_sch]
2024-08-25 Make some changes to the README
    [Hackboard.kicad_pcb]
2024-08-25 Rotate MCU and retrace
    [Hackboard.kicad_pcb, Hackboard.kicad_sch]
2024-08-26 Finish tracing, update 3d view, add punctuation & change wording in README
    [Hackboard.kicad_pcb]
2024-08-26 Slight change to silkscreen, remove config file
    [Hackboard.kicad_pcb]
2024-08-26 Change BOM
    [Hackboard.kicad_pcb, Hackboard.kicad_sch]
2024-08-31 Add power consumption data
2024-09-01 Update schematic, add layer previews
2024-09-01 Add schematic to images
